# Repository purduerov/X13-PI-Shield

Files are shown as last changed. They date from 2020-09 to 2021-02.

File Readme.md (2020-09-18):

# Readme for X13-PI-Shield

Whenever you make a new part, download the datasheet and save it here _**and**_ with the part in the parts library

Always pull other people's changes before beginning to work
`git pull`

Be sure to push your changes after  working on them. Run:
1. `git add .` to add any files in this directory or a subdirectory
or `git add -u` to add any modified files
2. (Optional) `git clean -nX` to see what ignored files can be removed
	`git clean -fX` removes ignored files (Eagle backups)
3. `git commit -m "helpful commit message"` with a description of the work that you did
4. `git push` to push your work to github

Other helpful commands
* `git status` says information about modified and staged files
* `git log` shows the recent commits of the repository
* `git log filename.extension` show the recent commits for just that file
* `git checkout first-couple-letter-of-commit-id` lets you go back to a previous version
* `git checkout master` brings you back to the latest commit
* `git tag` lists the tags
* `git tag -a orderX -m "the version of the board placed for the X'th order"` tag a specific commit
* `git push --tags` needed to push tags to remote
* `git show orderX` show the commit log for the given tag
* `git checkout orderX` go back and interact with the files at the tagged commit

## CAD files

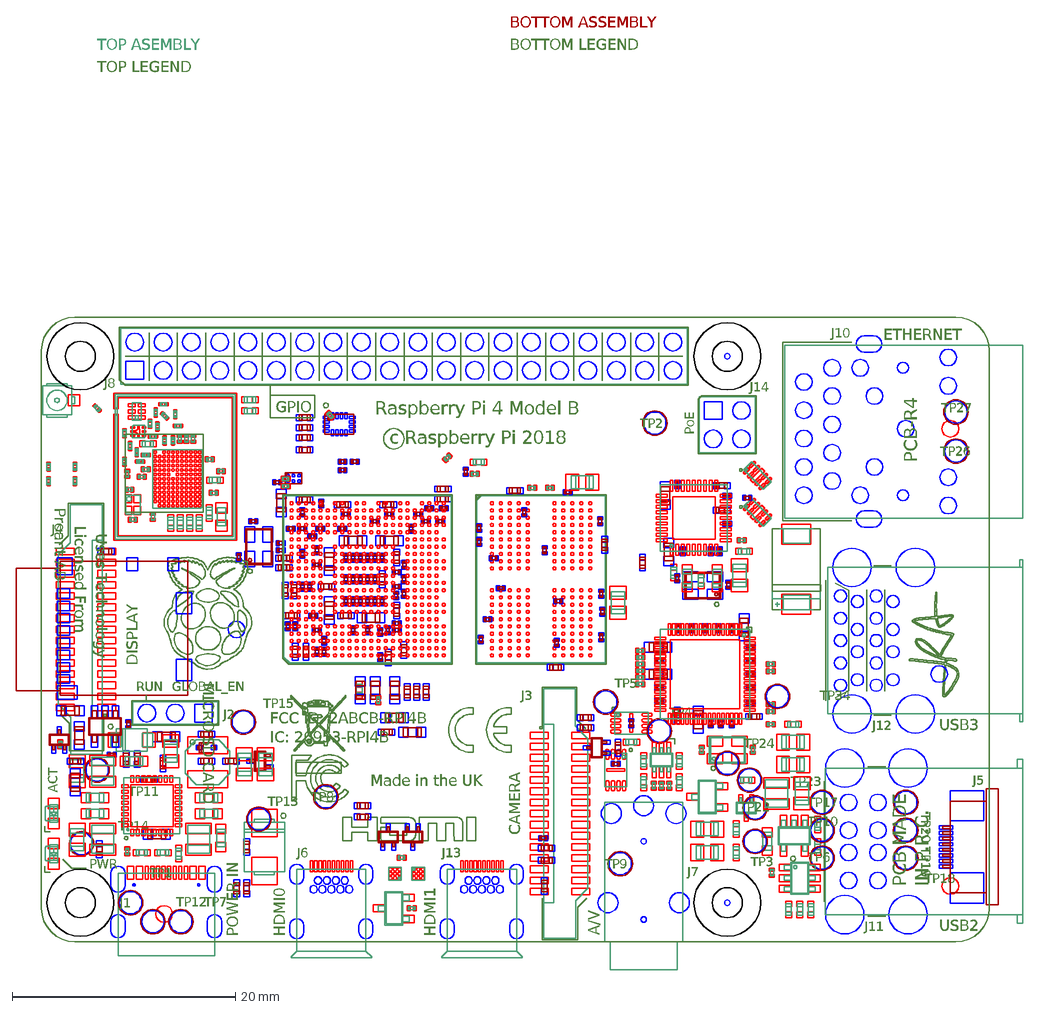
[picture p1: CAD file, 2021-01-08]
Pi Part/rpi_MECH_4b_4p0-with_mounting.dxf
TP20
TP19
TP18
TP17
TP10
TP6
TP5
TP34
TP15
TP14
TP13
TP11
TP8
TP7
TP24
TP23
TP22
TP12
TP9
TP4
TP3
TP2
TP1
TP27
TP26
J5
Made in the UK
IN P.R.C.
PCB MADE
IC: 20953-RPI4B
FCC ID: 2ABCB-RPI4B
PCB-R4
RUN
GLOBAL_EN
Proant AB
Licensed From
Uses Technology
MICRO SD CARD
GPIO
c Raspberry Pi 2018
Raspberry Pi 4 Model B
J2
J8
J14
J11
J12
J10
J7
J13
J3
J6
J1
J4
PoE
USB3
USB2
ETHERNET
A/V
DISPLAY
CAMERA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

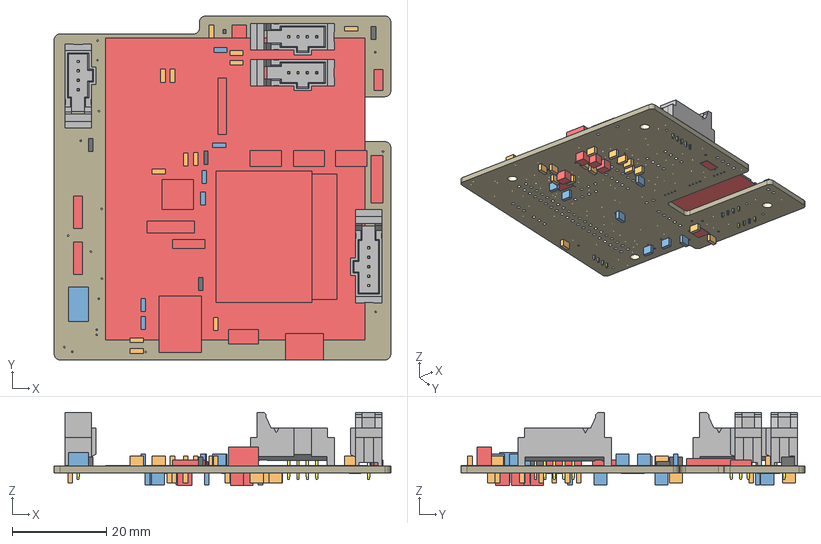
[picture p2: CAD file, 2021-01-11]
PI_Shield.step
71.5 x 73.0 x 15.5 mm
Board
0.1uF x 13
150uF
250mA/100V
COLOR
LED-0603 x 3
1X04 x 2
_T2I-04-VT-T-S-TH_terminal x 3
_T2I-04-VT-T-S-TH_pins x 3
DF13-4P-1.25DSA x 3
_T2I-05-VT-T-S-TH_terminal
_T2I-05-VT-T-S-TH_pins
1X03 x 3
1X05
1X02
1X02 (1) x 2
2.5A/30V/105mΩ x 5
MCP2515
TCAN337D
USB-MICRO
ADAFRUIT-FXOS8700-FXAS21002
ADAFRUIT-BNO055
DISCRETECOMPONENTS_SW_2512
MCR1101
RPI4
MAX1136EUA-T
AZ1117EH-3.3TRG1
ECS-80-S-4X

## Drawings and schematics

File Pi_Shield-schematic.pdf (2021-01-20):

A

A

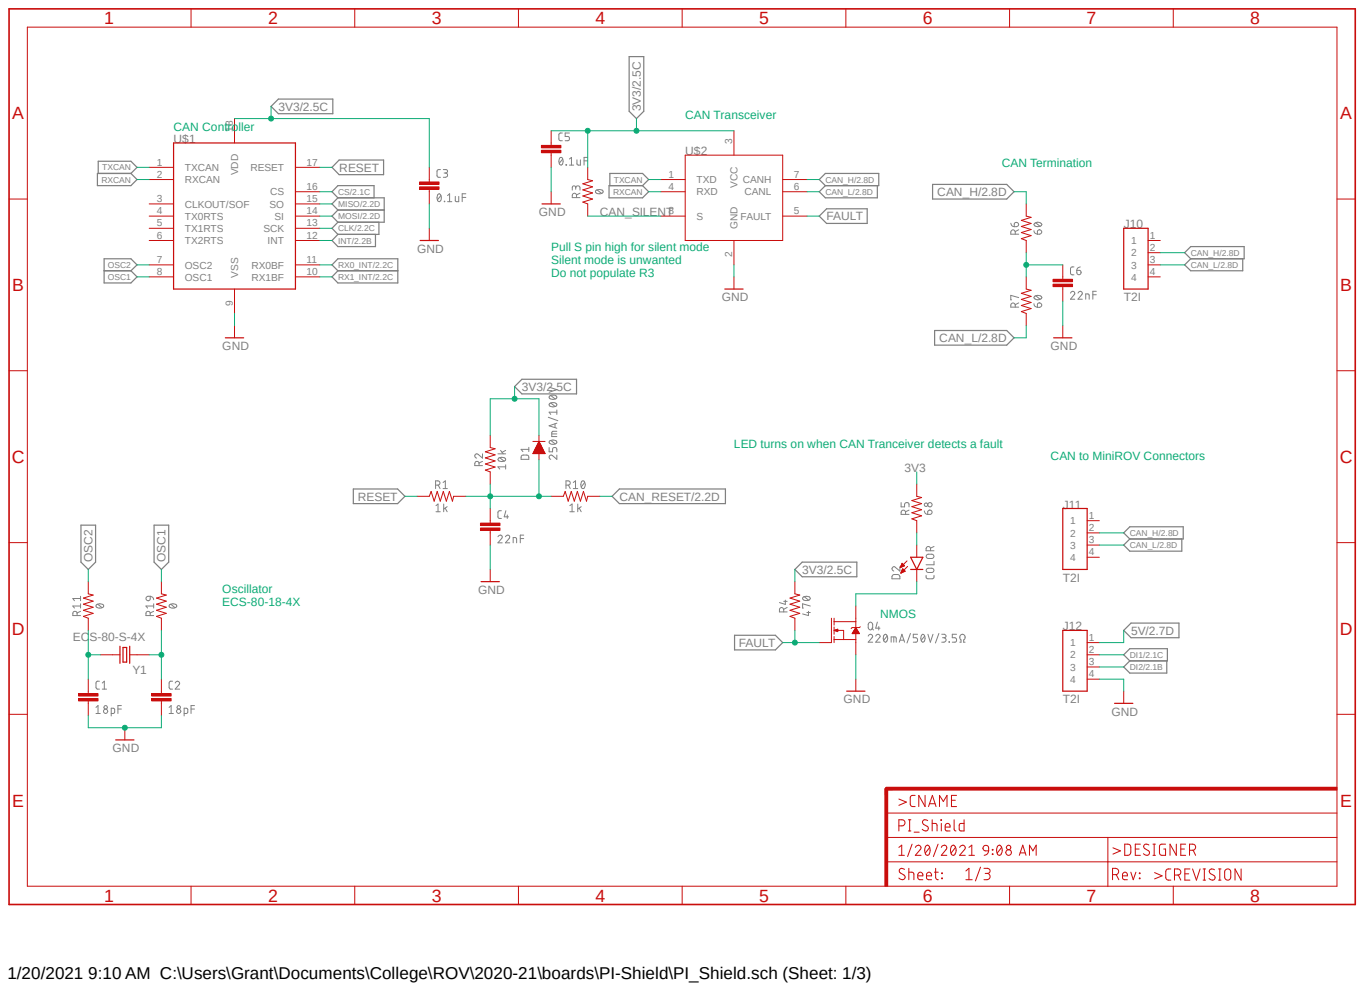
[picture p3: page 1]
ECS-80-S-4X; GND; TXCAN 1 RXCAN 2; CLKOUT/SOF 3 TX0RTS 4 TX1RTS 5 TX2RTS 6; OSC2 7; OSC1 8; VSS; INT; 12 SCK; RESET; 17 VDD ¹⁸; VCC; TXD 1; RXD 4; CANH; CANL; FAULT; RESET OSC¹; OSC1 OSC²; OSC2; TXCAN; RXCAN; CAN_H/2.8D; CAN_L/2.8D; CS/2.1C MISO/2.2D MOSI/2.2D CLK/2.2C; INT/2.2B; CAN_SILENT; RX0_INT/2.2C RX1_INT/2.2C; CAN_RESET/2.2D; Oscillator ECS-80-18-4X; CAN Termination; NMOS; CAN Controller; CAN Transceiver

Pull S pin high for silent mode
Silent mode is unwanted
Do not populate R3

LED turns on when CAN Tranceiver detects a fault

CAN to MiniROV Connectors

1/20/2021 9:10 AM C:\Users\Grant\Documents\College\ROV\2020-21\boards\PI-Shield\PI_Shield.sch (Sheet: 1/3)

A

A

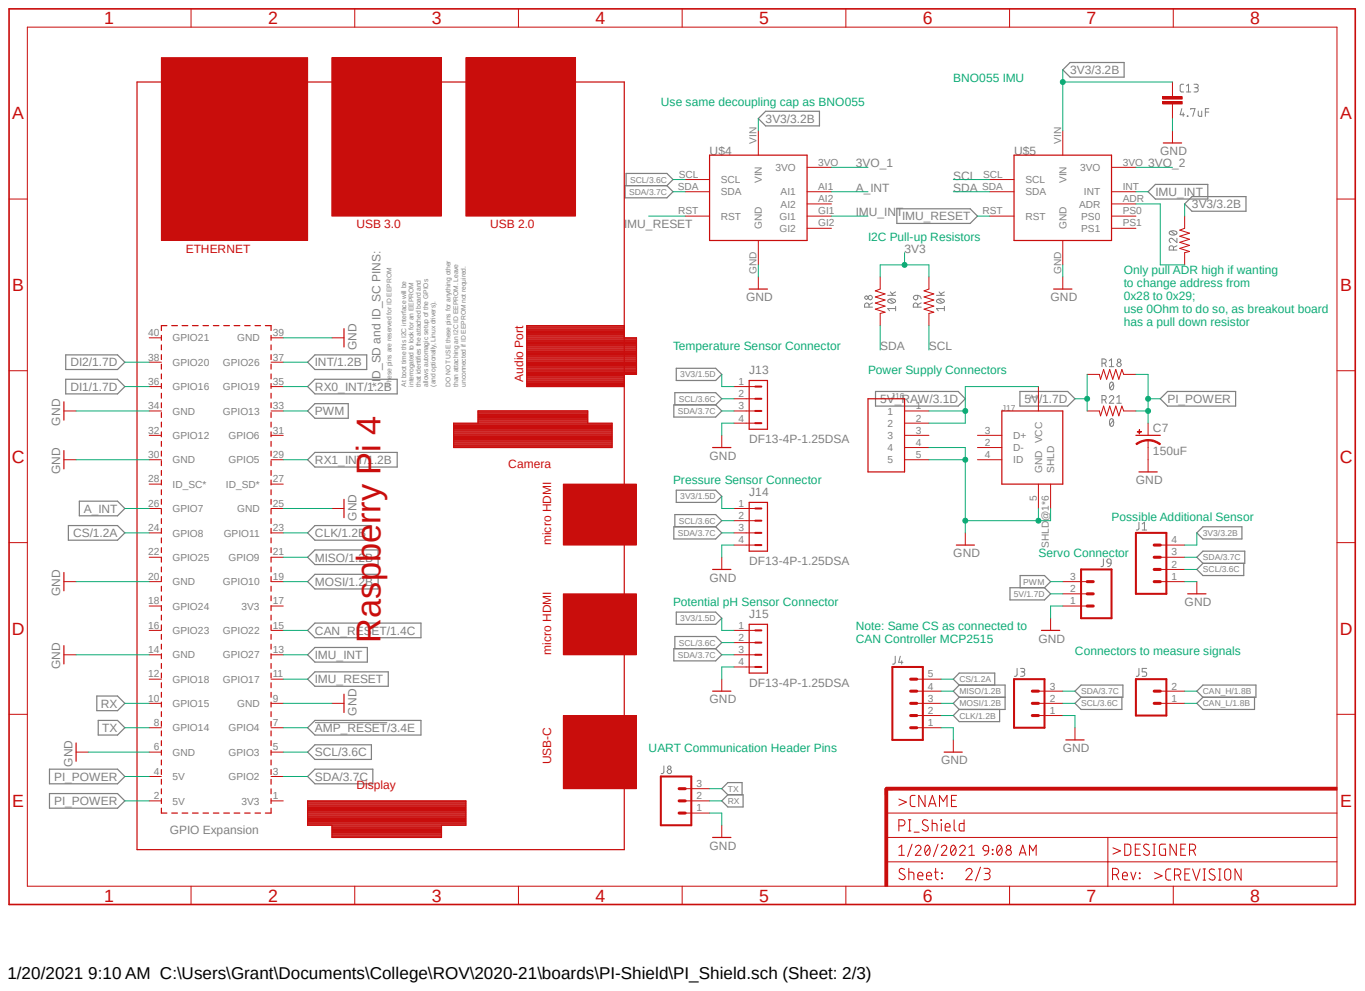
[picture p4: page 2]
DF13-4P-1.25DSA; GND; GND GND GND GND GND GND; GND GND GND; SCL SCL SDA SDA; RST RST; VIN VIN GND GND; INT; ADR; VCC; 1 GND; 5 SHLD SHLD@1*6; GPIO2 3; GPIO3 5 GND 6; GPIO4 7 GPIO14 8; GND 9 GPIO15 10; GPIO17 11 GPIO18 12; GPIO27 13 GND 14; GPIO22 15 GPIO23 16; 3V3 17 GPIO24 18; GPIO10 19 GND 20; GPIO9 21 GPIO25 22; GPIO11 23 GPIO8 24; GND 25 GPIO7 26; GPIO5 29 GND 30; GPIO6 31 GPIO12 32; GPIO13 33 GND 34; GPIO19 35 GPIO16 36; GPIO26 37 GPIO20 38; GND 39 GPIO21 40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

Use same decoupling cap as BNO055

3 C7 VIN VIN GND GND

Only pull ADR high if wanting
to change address from
use 0Ohm to do so, as breakout board
has a pull down resistor

Temperature Sensor Connector

SDA
Power Supply Connectors

Possible Additional Sensor

DF13-4P-1.25DSA
GND
Potential pH Sensor Connector

Note: Same CS as connected to
CAN Controller MCP2515

Connectors to measure signals

UART Communication Header Pins

1/20/2021 9:10 AM C:\Users\Grant\Documents\College\ROV\2020-21\boards\PI-Shield\PI_Shield.sch (Sheet: 2/3)

A

A

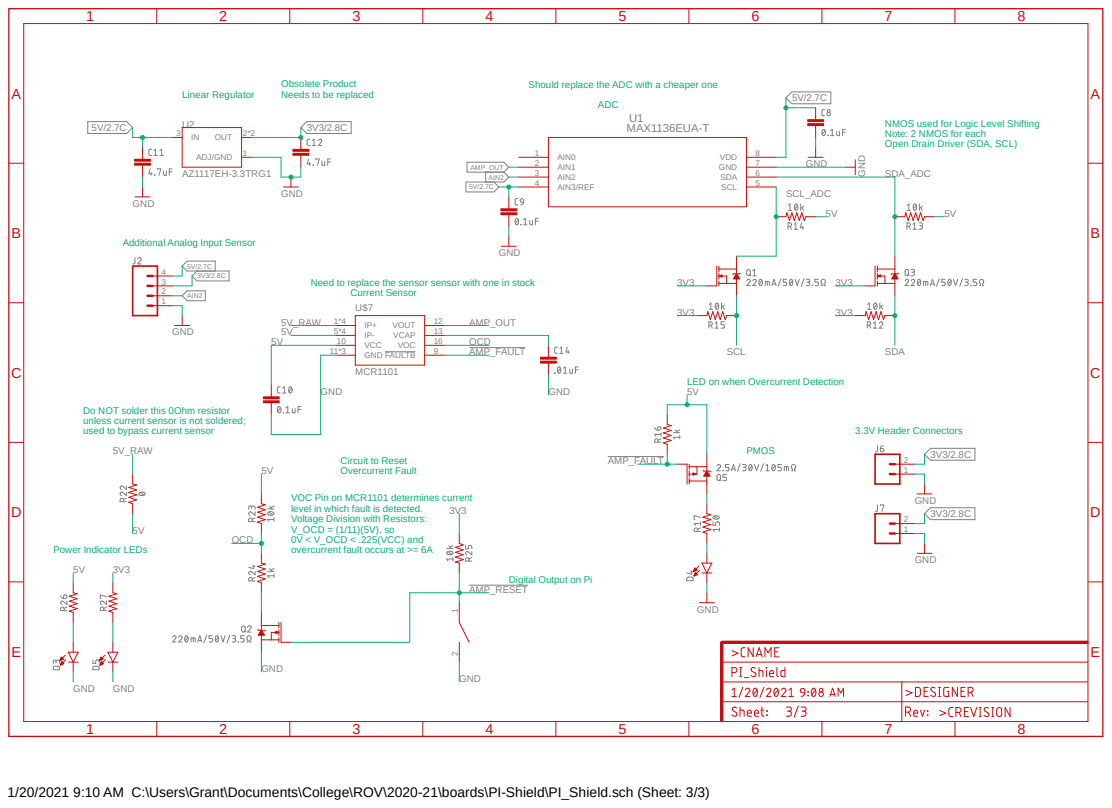
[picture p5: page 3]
MAX1136EUA-T; AZ1117EH-3.3TRG1; GND; MCR1101; AIN0 1 AIN1 2 AIN2 3; AIN3/REF 4; SCL; SDA; VDD; ADJ/GND; OUT; IP+ 1*4 IP- 5*4 VCC 10 GND 11*3; VOUT; VCAP; VOC; FAULTB; 1 2 GND GND; SCL_ADC; SDA_ADC; AMP_OUT; AIN2; 5V_RAW; OCD; AMP_RESET; AMP_FAULT; ADC; 3.3V Header Connectors; PMOS; Linear Regulator; Current Sensor; Obsolete Product; Should replace the ADC with a cheaper one

Needs to be replaced

NMOS used for Logic Level Shifting
Note: 2 NMOS for each
Open Drain Driver (SDA, SCL)

Additional Analog Input Sensor

Need to replace the sensor sensor with one in stock

LED on when Overcurrent Detection

Do NOT solder this 0Ohm resistor
unless current sensor is not soldered;
used to bypass current sensor
5V_RAW

Circuit to Reset
Overcurrent Fault

VOC Pin on MCR1101 determines current
level in which fault is detected.
Voltage Division with Resistors:
V_OCD = (1/11)(5V), so
0V < V_OCD < .225(VCC) and
overcurrent fault occurs at >= 6A

Power Indicator LEDs

Digital Output on Pi

1/20/2021 9:10 AM C:\Users\Grant\Documents\College\ROV\2020-21\boards\PI-Shield\PI_Shield.sch (Sheet: 3/3)

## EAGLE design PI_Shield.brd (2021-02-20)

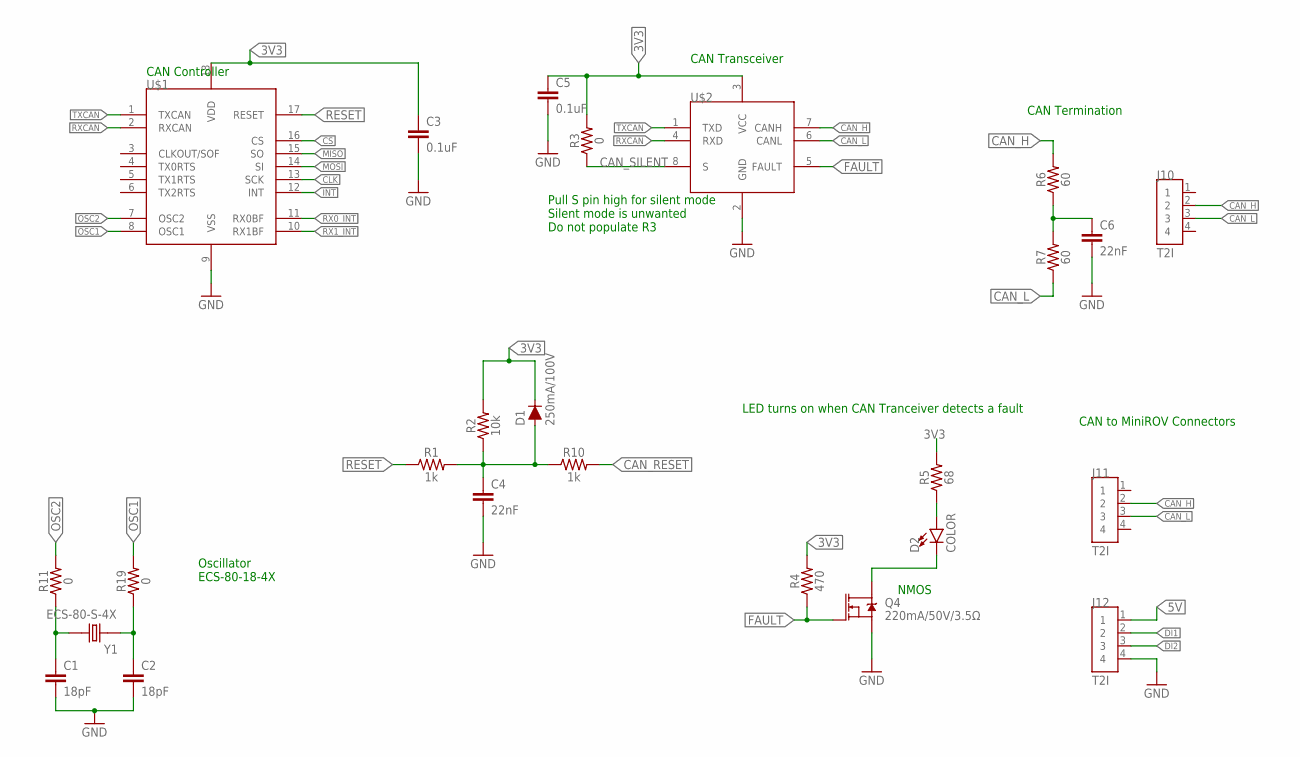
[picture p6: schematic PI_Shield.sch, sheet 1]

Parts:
C1, C2: 18pF; 0603
C3, C5: 0.1uF; 0603
C4, C6: 22nF; 0603
D1: 250mA/100V; SOD-323
D2: COLOR; 0805
J10, J11, J12: T2I
Q4: 220mA/50V/3.5Ω; SOT23-3
R1, R10: 1k; 0603
R2: 10k; 0603
R3, R11, R19: 0; 0603
R4: 470; 0603
R5: 68; 0603
R6, R7: 60; 0603
U$1: MCP2515; SOIC-18
U$2: TCAN337D; SOIC-8
Y1: ECS-80-S-4X; XTAL_ECS-80-S-4X

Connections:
3V3: C3.1, C5.1, D1.C, R2.2, R3.2, R4.2, R5.2, U$1.18 (VDD), U$2.3 (VCC); also elsewhere on the board
5V: J12.1; also elsewhere on the board
CAN_H: J10.2, J11.2, R6.2, U$2.7 (CANH); also elsewhere on the board
CAN_L: J10.3, J11.3, R7.1, U$2.6 (CANL); also elsewhere on the board
CAN_RESET: R10.2; also elsewhere on the board
CAN_SILENT: R3.1, U$2.8 (S)
CAN_TERM_COM: C6.1, R6.1, R7.2
CLK: U$1.13 (SCK); also elsewhere on the board
CS: U$1.16 (CS); also elsewhere on the board
DI1: J12.2; also elsewhere on the board
DI2: J12.3; also elsewhere on the board
FAULT: Q4.1 (G), R4.1, U$2.5 (FAULT)
GND: C1.2, C2.2, C3.2, C4.2, C5.2, C6.2, J12.4, Q4.2 (S), U$1.9 (VSS), U$2.2 (GND); also elsewhere on the board
INT: U$1.12 (INT); also elsewhere on the board
MISO: U$1.15 (SO); also elsewhere on the board
MOSI: U$1.14 (SI); also elsewhere on the board
unnamed: C1.1, R11.1, Y1.2
unnamed: C2.1, R19.1, Y1.1
unnamed: D2.C, Q4.3 (D)
unnamed: D2.A, R5.1
OSC1: R19.2, U$1.8 (OSC1)
OSC2: R11.2, U$1.7 (OSC2)
RESET: R1.1, U$1.17 (RESET)
RESET_MID: C4.1, D1.A, R1.2, R2.1, R10.1
RX0_INT: U$1.11 (RX0BF); also elsewhere on the board
RX1_INT: U$1.10 (RX1BF); also elsewhere on the board
RXCAN: U$1.2 (RXCAN), U$2.4 (RXD)
TXCAN: U$1.1 (TXCAN), U$2.1 (TXD)

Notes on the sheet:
Oscillator ECS-80-18-4X
CAN Termination
CAN to MiniROV Connectors
NMOS
CAN Controller
CAN Transceiver
Pull S pin high for silent mode Silent mode is unwanted Do not populate R3
LED turns on when CAN Tranceiver detects a fault

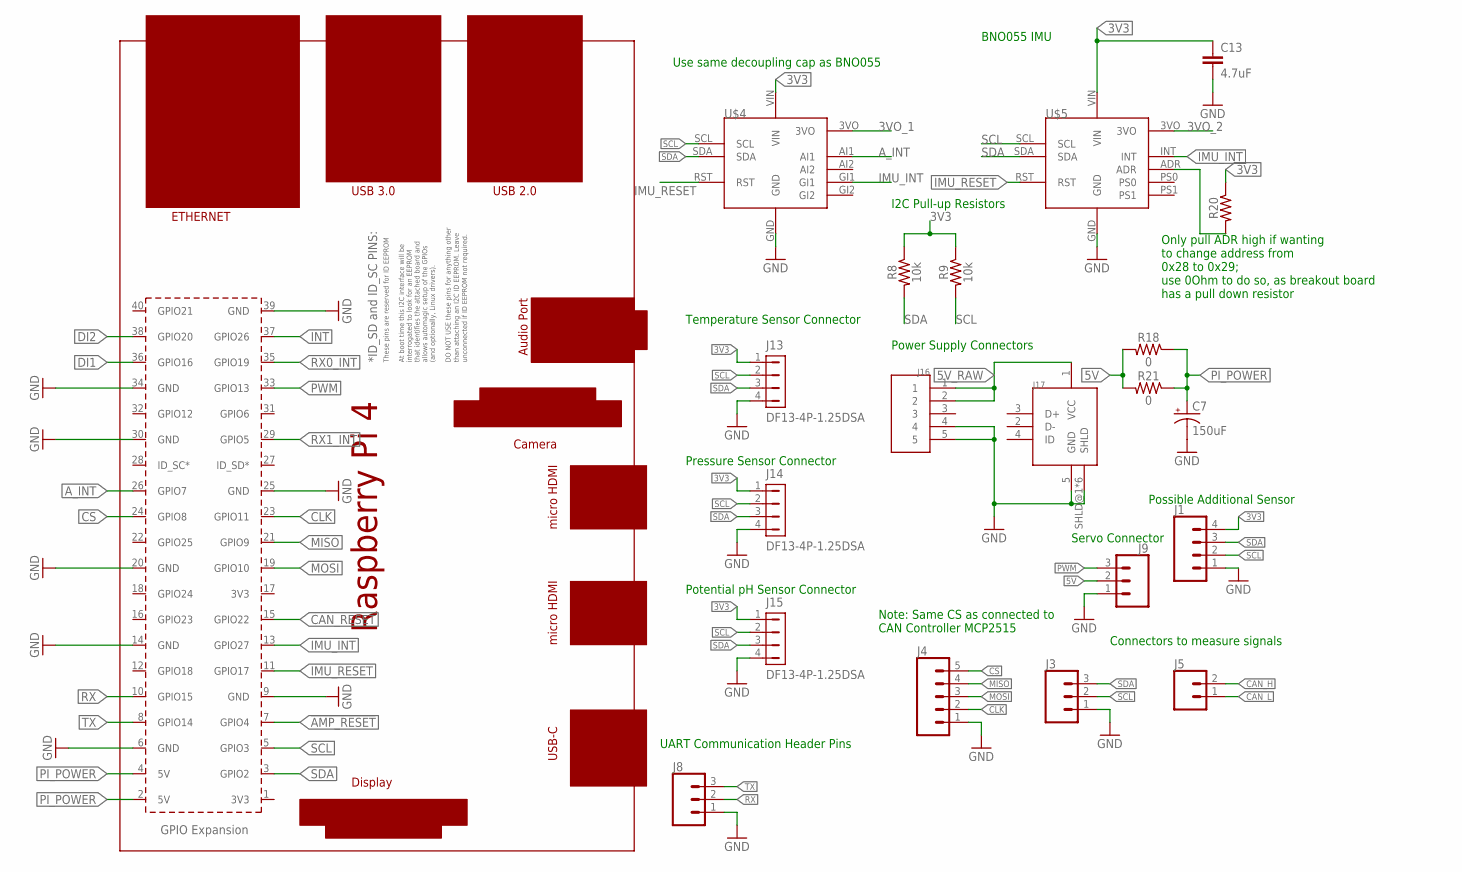
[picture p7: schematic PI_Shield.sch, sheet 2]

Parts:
C7: 150uF; 2917(7343-31-METRIC)
C13: 4.7uF; 0603
J1: CONN_04; 1X04
J3, J8, J9: CONN_03; 1X03
J4: CONN_05; 1X05
J5: CONN_02; 1X02
J13, J14, J15: DF13-4P-1.25DSA
J16: T2I5P
J17: USB-MICRO; MICRO-USB
R8, R9: 10k; 0603
R18, R21: 0; 0603
R20: RESISTOR0603; 0603
U$4: ADAFRUIT-FXOS8700-FXAS21002
U$5: ADAFRUIT-BNO055
U$8: RPI4

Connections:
3V3: C13.1, J1.4, J13.1, J14.1, J15.1, R8.1, R9.1, R20.1, U$4.VIN, U$5.VIN; also elsewhere on the board
3VO_1: U$4.3VO
3VO_2: U$5.3VO
5V: J9.2, R18.2, R21.2; also elsewhere on the board
5V_RAW: J16.1, J16.2, J17.1 (VCC); also elsewhere on the board
!AMP_RESET: U$8.7 (GPIO4); also elsewhere on the board
A_INT: U$4.AI1, U$8.26 (GPIO7)
CAN_H: J5.2; also elsewhere on the board
CAN_L: J5.1; also elsewhere on the board
CAN_RESET: U$8.15 (GPIO22); also elsewhere on the board
CLK: J4.2, U$8.23 (GPIO11); also elsewhere on the board
CS: J4.5, U$8.24 (GPIO8); also elsewhere on the board
DI1: U$8.36 (GPIO16); also elsewhere on the board
DI2: U$8.38 (GPIO20); also elsewhere on the board
GND: C7.-, C13.2, J1.1, J3.1, J4.1, J8.1, J9.1, J13.4, J14.4, J15.4, J16.4, J16.5, J17.5 (GND), J17.SHLD@1 (SHLD), J17.SHLD@2 (SHLD), J17.SHLD@3 (SHLD), J17.SHLD@4 (SHLD), J17.SHLD@5 (SHLD), J17.SHLD@6 (SHLD), U$4.GND, U$5.GND, U$8.6 (GND), U$8.9 (GND), U$8.14 (GND), U$8.20 (GND), U$8.25 (GND), U$8.30 (GND), U$8.34 (GND), U$8.39 (GND); also elsewhere on the board
IMU_INT: U$4.GI1, U$5.INT, U$8.13 (GPIO27)
IMU_RESET: U$4.RST, U$5.RST, U$8.11 (GPIO17)
INT: U$8.37 (GPIO26); also elsewhere on the board
MISO: J4.4, U$8.21 (GPIO9); also elsewhere on the board
MOSI: J4.3, U$8.19 (GPIO10); also elsewhere on the board
unnamed: R20.2, U$5.ADR
PI_POWER: C7.+, R18.1, R21.1, U$8.2 (5V), U$8.4 (5V)
PWM: J9.3, U$8.33 (GPIO13)
RX: J8.2, U$8.10 (GPIO15)
RX0_INT: U$8.35 (GPIO19); also elsewhere on the board
RX1_INT: U$8.29 (GPIO5); also elsewhere on the board
SCL: J1.2, J3.2, J13.2, J14.2, J15.2, R9.2, U$4.SCL, U$5.SCL, U$8.5 (GPIO3); also elsewhere on the board
SDA: J1.3, J3.3, J13.3, J14.3, J15.3, R8.2, U$4.SDA, U$5.SDA, U$8.3 (GPIO2); also elsewhere on the board
TX: J8.3, U$8.8 (GPIO14)

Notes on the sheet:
Connectors to measure signals
Temperature Sensor Connector
Pressure Sensor Connector
Potential pH Sensor Connector
BNO055 IMU
Power Supply Connectors
Possible Additional Sensor
UART Communication Header Pins
Servo Connector
Only pull ADR high if wanting to change address from 0x28 to 0x29; use 0Ohm to do so, as breakout board has a pull down resistor
Use same decoupling cap as BNO055
I2C Pull-up Resistors
Note: Same CS as connected to CAN Controller MCP2515

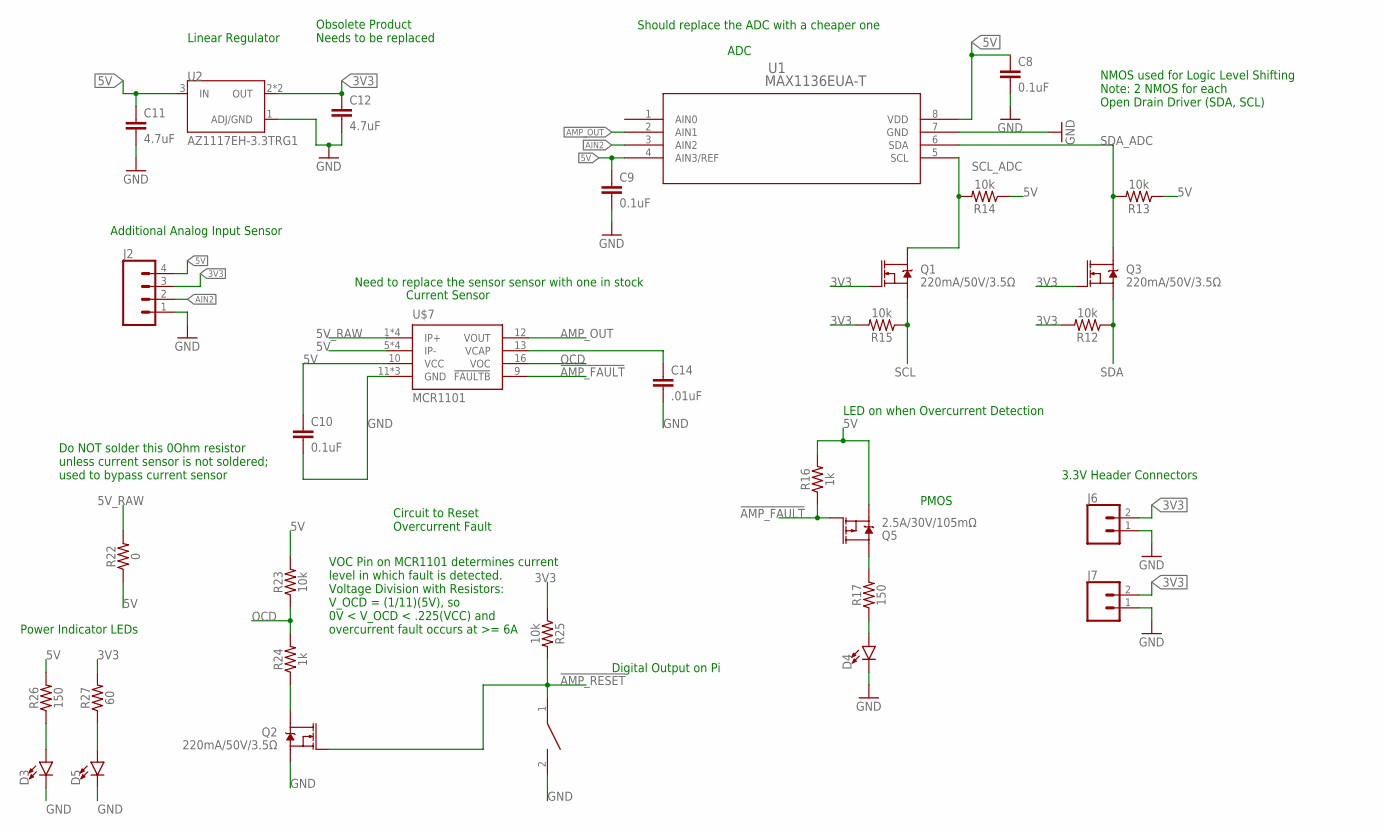
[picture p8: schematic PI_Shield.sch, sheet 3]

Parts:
C8, C9, C10: 0.1uF; 0603
C11, C12: 4.7uF; 0603
C14: .01uF; 0603
D3, D4, D5: LED0603; LED-0603
J2: CONN_04; 1X04
J6, J7: CONN_02; 1X02
Q1, Q2, Q3: 220mA/50V/3.5Ω; SOT23-3
Q5: 2.5A/30V/105mΩ; SOT23-3
R12, R13, R14, R15, R23, R25: 10k; 0603
R16, R24: 1k; 0603
R17, R26: 150; 0603
R22: 0; 0603
R27: 60; 0603
U1: MAX1136EUA-T; 21-0036K
U2: AZ1117EH-3.3TRG1; SOT230P700X180-4N
U$6: DISCRETECOMPONENTS_SWITCH; DISCRETECOMPONENTS_SW_2512
U$7: MCR1101; SOIC-16

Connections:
3V3: C12.1, J2.3, J6.2, J7.2, Q1.1 (G), Q3.1 (G), R12.2, R15.2, R25.1, R27.2, U2.2 (OUT), U2.4 (OUT); also elsewhere on the board
5V: C8.1, C9.1, C10.1, C11.1, J2.4, Q5.2 (S), R13.1, R14.1, R16.2, R22.1, R23.2, R26.2, U1.4 (AIN3/REF), U1.8 (VDD), U2.3 (IN), U$7.5 (IP-), U$7.6 (IP-), U$7.7 (IP-), U$7.8 (IP-), U$7.10 (VCC); also elsewhere on the board
5V_RAW: R22.2, U$7.1 (IP+), U$7.2 (IP+), U$7.3 (IP+), U$7.4 (IP+); also elsewhere on the board
!AMP_FAULT: Q5.1 (G), R16.1, U$7.9 (!FAULTB)
!AMP_RESET: Q2.1 (G), R25.2, U$6.1; also elsewhere on the board
AIN2: J2.2, U1.3 (AIN2)
AMP_OUT: U1.2 (AIN1), U$7.12 (VOUT)
GND: C8.2, C9.2, C10.2, C11.2, C12.2, C14.2, D3.C, D4.C, D5.C, J2.1, J6.1, J7.1, Q2.2 (S), U1.7 (GND), U2.1 (ADJ/GND), U$6.2, U$7.11 (GND), U$7.14 (GND), U$7.15 (GND); also elsewhere on the board
unnamed: C14.1, U$7.13 (VCAP)
unnamed: D3.A, R26.1
unnamed: Q5.3 (D), R17.2
unnamed: D4.A, R17.1
unnamed: D5.A, R27.1
unnamed: Q2.3 (D), R24.1
OCD: R23.1, R24.2, U$7.16 (VOC)
SCL: Q1.2 (S), R15.1; also elsewhere on the board
SCL_ADC: Q1.3 (D), R14.2, U1.5 (SCL)
SDA: Q3.2 (S), R12.1; also elsewhere on the board
SDA_ADC: Q3.3 (D), R13.2, U1.6 (SDA)

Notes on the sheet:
ADC
Additional Analog Input Sensor
3.3V Header Connectors
PMOS
LED on when Overcurrent Detection
NMOS used for Logic Level Shifting Note: 2 NMOS for each Open Drain Driver (SDA, SCL)
Linear Regulator
Do NOT solder this 0Ohm resistor unless current sensor is not soldered; used to bypass current sensor
Current Sensor
Circuit to Reset Overcurrent Fault
Need to replace the sensor sensor with one in stock
Should replace the ADC with a cheaper one
Obsolete Product Needs to be replaced
Power Indicator LEDs
VOC Pin on MCR1101 determines current level in which fault is detected. Voltage Division with Resistors: V_OCD = (1/11)(5V), so 0V < V_OCD < .225(VCC) and overcurrent fault occurs at >= 6A
Digital Output on Pi

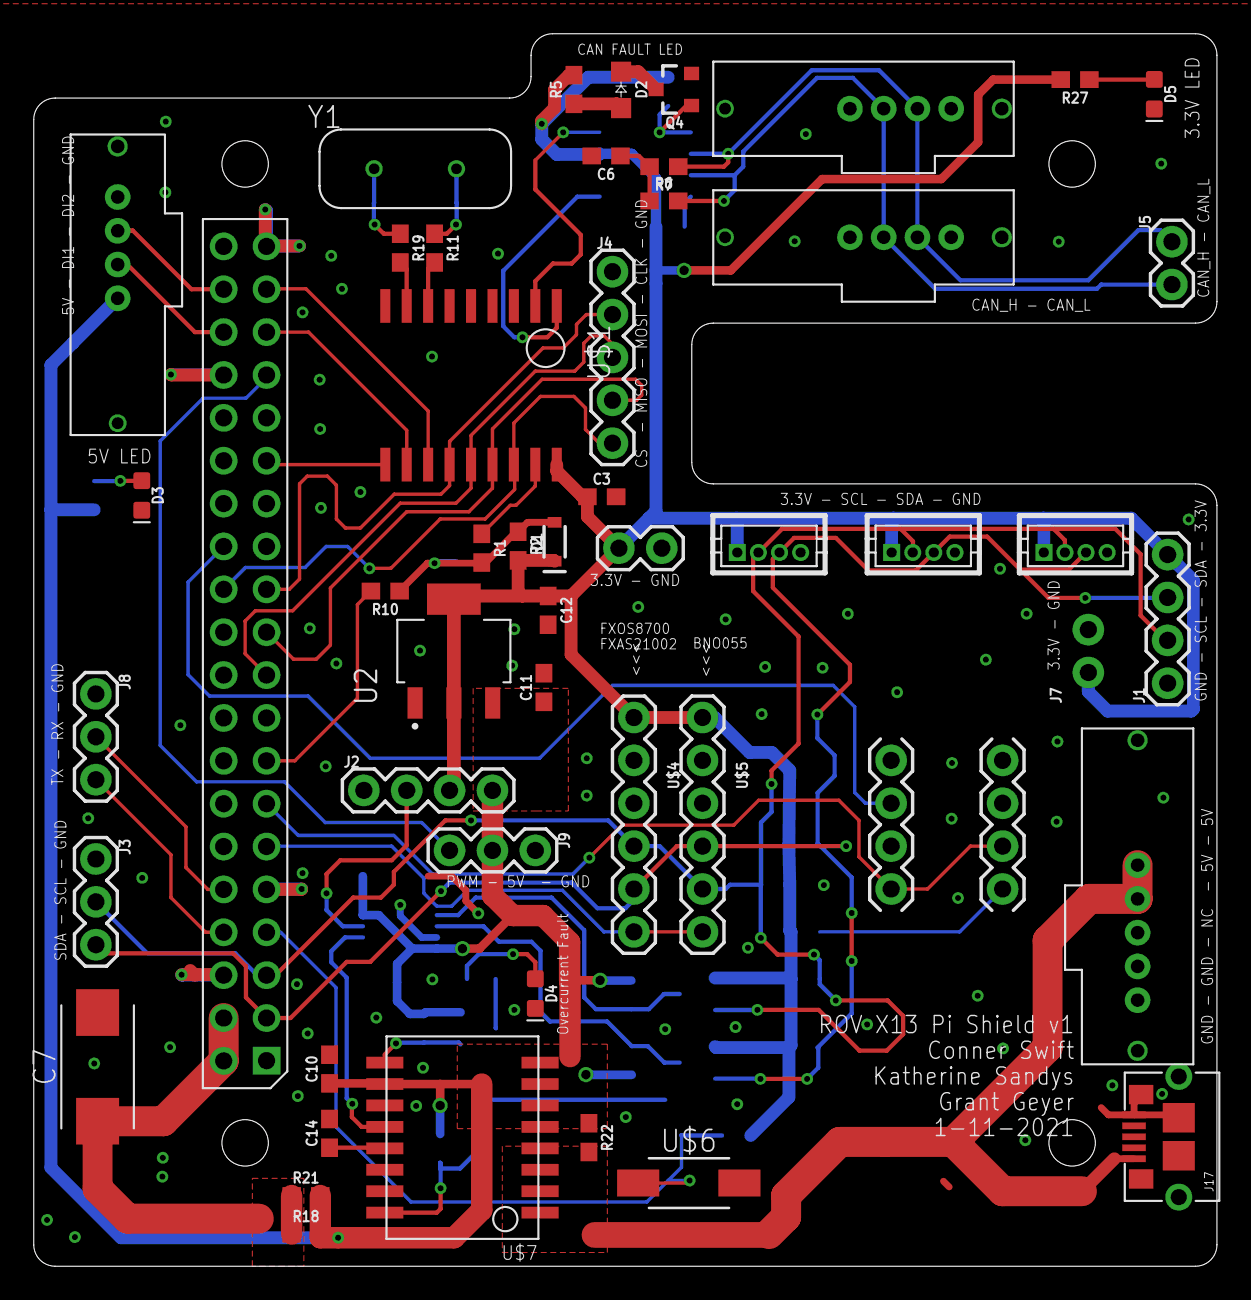
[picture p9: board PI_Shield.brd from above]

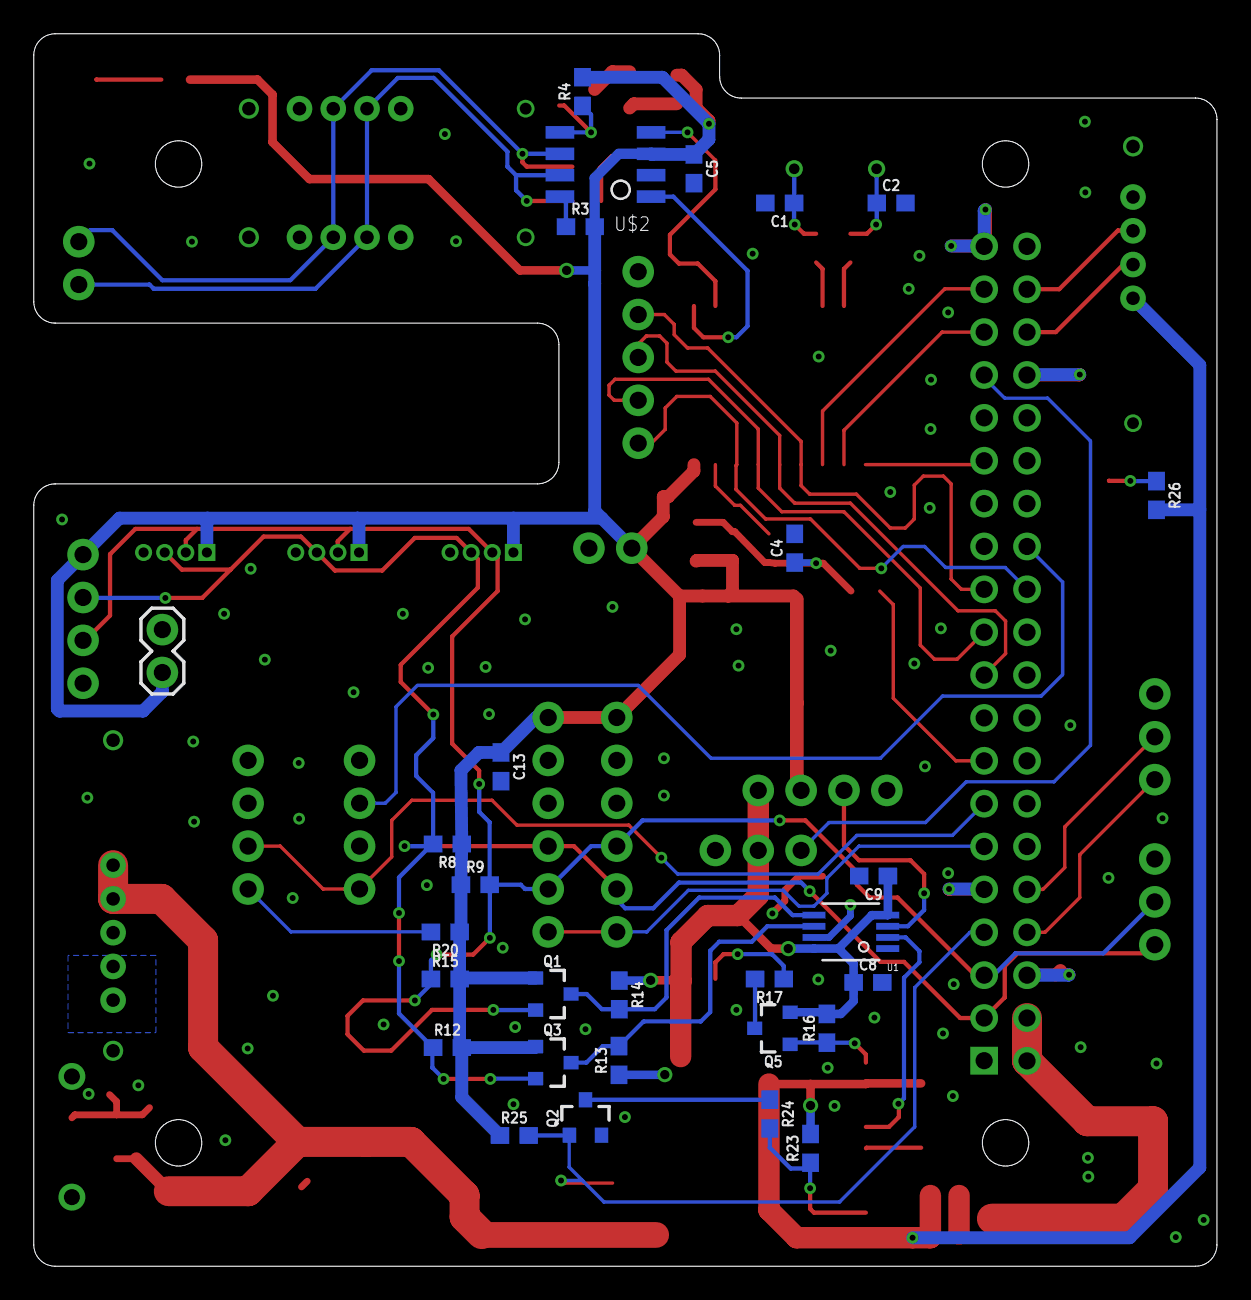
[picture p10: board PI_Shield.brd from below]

Board: 2 copper layers, 70.1 x 73.0 mm, 78 parts (29 on the bottom side), 52 nets.

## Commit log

2020-12-12 schematic touch ups, new IMU, smaller board
    [PI_Shield.brd, PI_Shield.sch]
2020-12-12 add micro usb connector for external powering while testing
    [PI_Shield.brd, PI_Shield.sch]
2020-12-12 update bno055 footprint
    [PI_Shield.brd, PI_Shield.sch]
2021-01-08 Added Part Datasheets and Pi 4 DXF Model
    [rpi_MECH_4b_4p0-with_mounting.dxf]
2021-01-08 Added Pi 4 and Current Sensor; Routed Interrupt pins signals to Pi
    [PI_Shield.brd, PI_Shield.sch]
2021-01-08 Started layout
    [PI_Shield.brd, PI_Shield.sch]
2021-01-09 Continuing Layout
    [PI_Shield.brd, PI_Shield.sch]
2021-01-09 Finished Layout
    [PI_Shield.brd, PI_Shield.sch]
2021-01-09 Started routing
    [PI_Shield.brd, PI_Shield.sch]
2021-01-09 routed some
    [PI_Shield.brd, PI_Shield.sch]
2021-01-10 General routing complete
    [PI_Shield.brd, PI_Shield.sch]
2021-01-10 Working on Impedance Matching
    [PI_Shield.brd]
2021-01-11 labels, routing touch ups, etc
    [PI_Shield.brd, PI_Shield.sch]
2021-01-11 Finishing touches
    [PI_Shield.brd, PI_Shield.sch]
2021-01-11 Added Image
    [PI_Shield.brd]
2021-01-11 Ordering text, step, and pdf
    [PI_Shield.brd, PI_Shield.sch, PI_Shield.step]
2021-01-12 naming USB connector and add notes for next year of which ICs to replace
    [PI_Shield.brd, PI_Shield.sch]
2021-01-20 Fixed Swapped IMUs on Schematic
    [PI_Shield.brd, PI_Shield.sch]
2021-01-20 Updated Parts from Updated X13 Parts Library
    [PI_Shield.brd, PI_Shield.sch]
2021-01-20 Added more notes to schematic
    [PI_Shield.sch]
2021-01-20 Fix misprint on schematic
2021-02-20 Move USB connector for accessbility and shrink left side for more clearance
    [PI_Shield.brd]
2021-02-20 Added Resistor Values to Power Indicator LED circuits
    [PI_Shield.brd, PI_Shield.sch]

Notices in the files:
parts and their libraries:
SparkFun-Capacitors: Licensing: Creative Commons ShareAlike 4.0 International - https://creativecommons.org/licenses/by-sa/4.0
